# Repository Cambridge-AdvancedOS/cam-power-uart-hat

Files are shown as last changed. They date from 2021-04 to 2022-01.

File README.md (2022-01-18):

# Raspberry Pi Serial and Power Switching Hat

A Raspberry Pi Hat that provides USB serial access to the Pi's serial console. It allows for both power injection and switching via a JST-XH connector. There is also a combo temperature sensor/eeprom that can be accessed over USB.

Created for the [L41 Advanced Operating Systems](https://www.cl.cam.ac.uk/teaching/2021/L41/) course at UCAM CST.

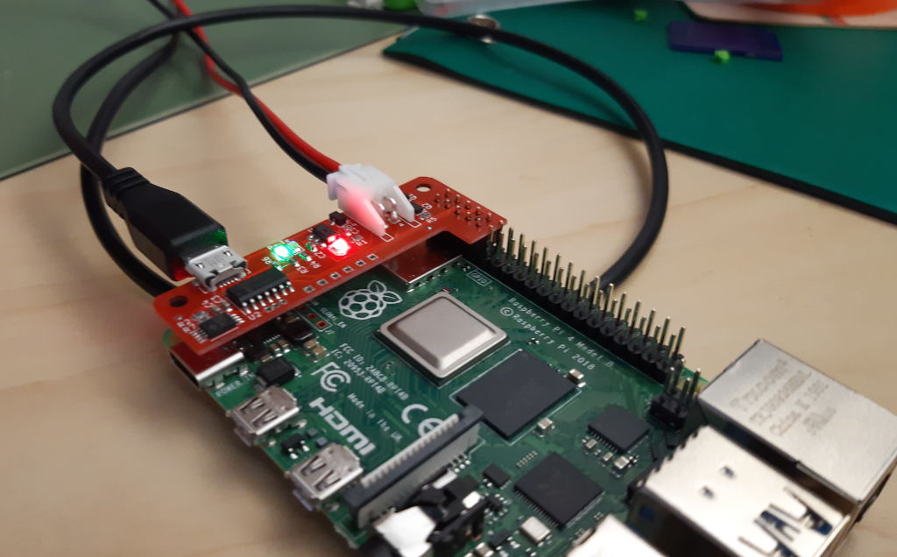
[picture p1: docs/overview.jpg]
Overview image showing the power hat attached to a RPi 4B


## Board Details

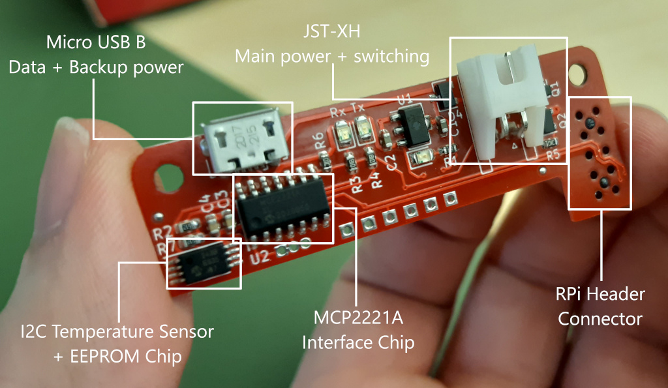
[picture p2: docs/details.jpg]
Detail view of the PCB with various chips labelled


### Notable ICs
* [MCP2221A](./docs/mcp2221a.pdf) - USB UART Interface chip, provides USB communications, GPIO control used for status LEDs and the power switching, and I2C interfacing to control the temperature sensor/eeprom.
* [MCP98243](./docs/mcp98243.pdf) - I2C temperature sensor and eeprom chip accessible via the MCP2221A. Could be substituted for other I2C chips as long as the power/GND and I2C pins match.
* [RQ5C060BC](./docs/rq5c060bc.pdf) - High power Pch MOSFET, can be substituted for any other high power (min 3A) MOSFET with a low gate threshold (must fully activate at Vgs = 3v3) and a GSD pin arrangement.

### Connectors
* Micro USB - Provides USB data and can provide power to the onboard ICs in the absense of the JST connector. No power is passed forward to the RPi however, so it cannot be powered from a single USB cable.
* [JST-XH](./docs/jst-xh.pdf) - Main power supply for the RPi, cables should be fitted with XHP-2 connectors with +ve on pin 1 and -ve on pin 2.
* RPi connector - Fits to the top end of the RPi GPIO header, uses a minimum of pins and leaves the remainder for other interaction.

## License

Designed by Thomas Bytheway for University of Cambridge.

Schematic details inspired by:
### [Adafruit-MCP2221](https://github.com/adafruit/Adafruit-MCP2221-PCB)
Designed by Limor Fried/Ladyada for Adafruit Industries.

### [Adafruit-PiUART](https://github.com/adafruit/Adafruit-PiUART-PCB)
Designed by Limor Fried/Ladyada for Adafruit Industries.

Creative Commons Attribution/Share-Alike, all text above must be included in any redistribution. See license.txt for additional details.

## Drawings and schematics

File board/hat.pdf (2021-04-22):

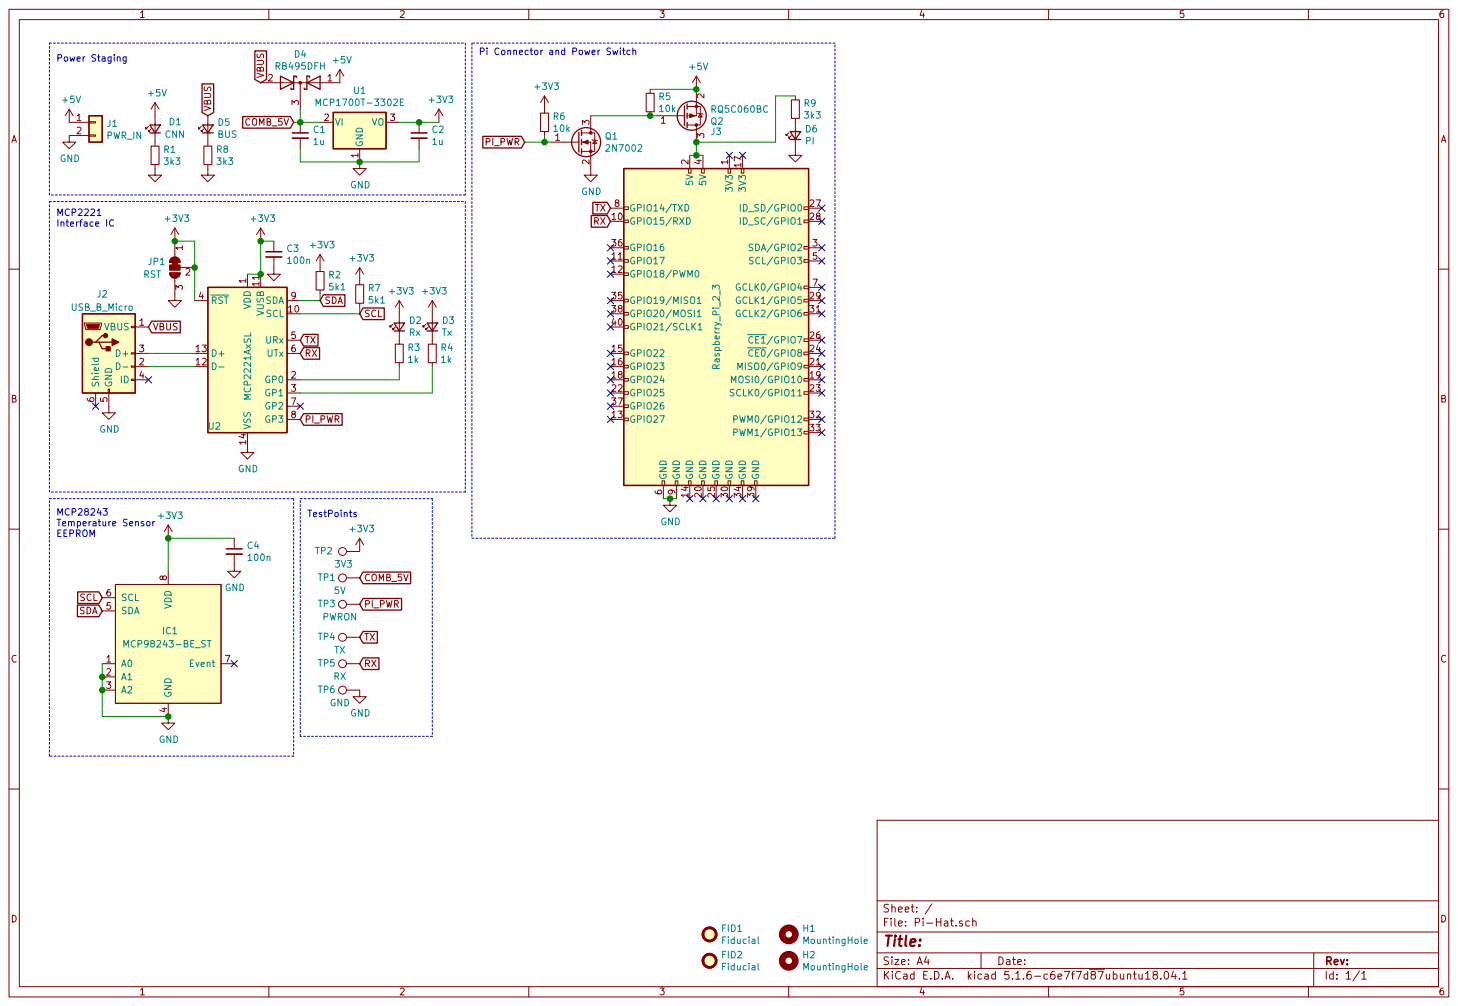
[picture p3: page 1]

TXRX VBUS
3k3 D5 BUS
Interface IC MCP28243 Temperature Sensor EEPROM

Pi Connector and Power Switch Power Staging MCP2221

1 SCL VUSB 10 11 D- 12 D+ 13 VSS 14 GP0 2 GP1 3 RST 4 URx 5 UTx 6 GP2 7 GP3 8 SDA 9 U2 MCP2221AxSL TP5RX

4 SDA 5 SCL 6 Event 7 VDD

Id: 1/1 Title: File: Pi-Hat.sch Sheet: / GND

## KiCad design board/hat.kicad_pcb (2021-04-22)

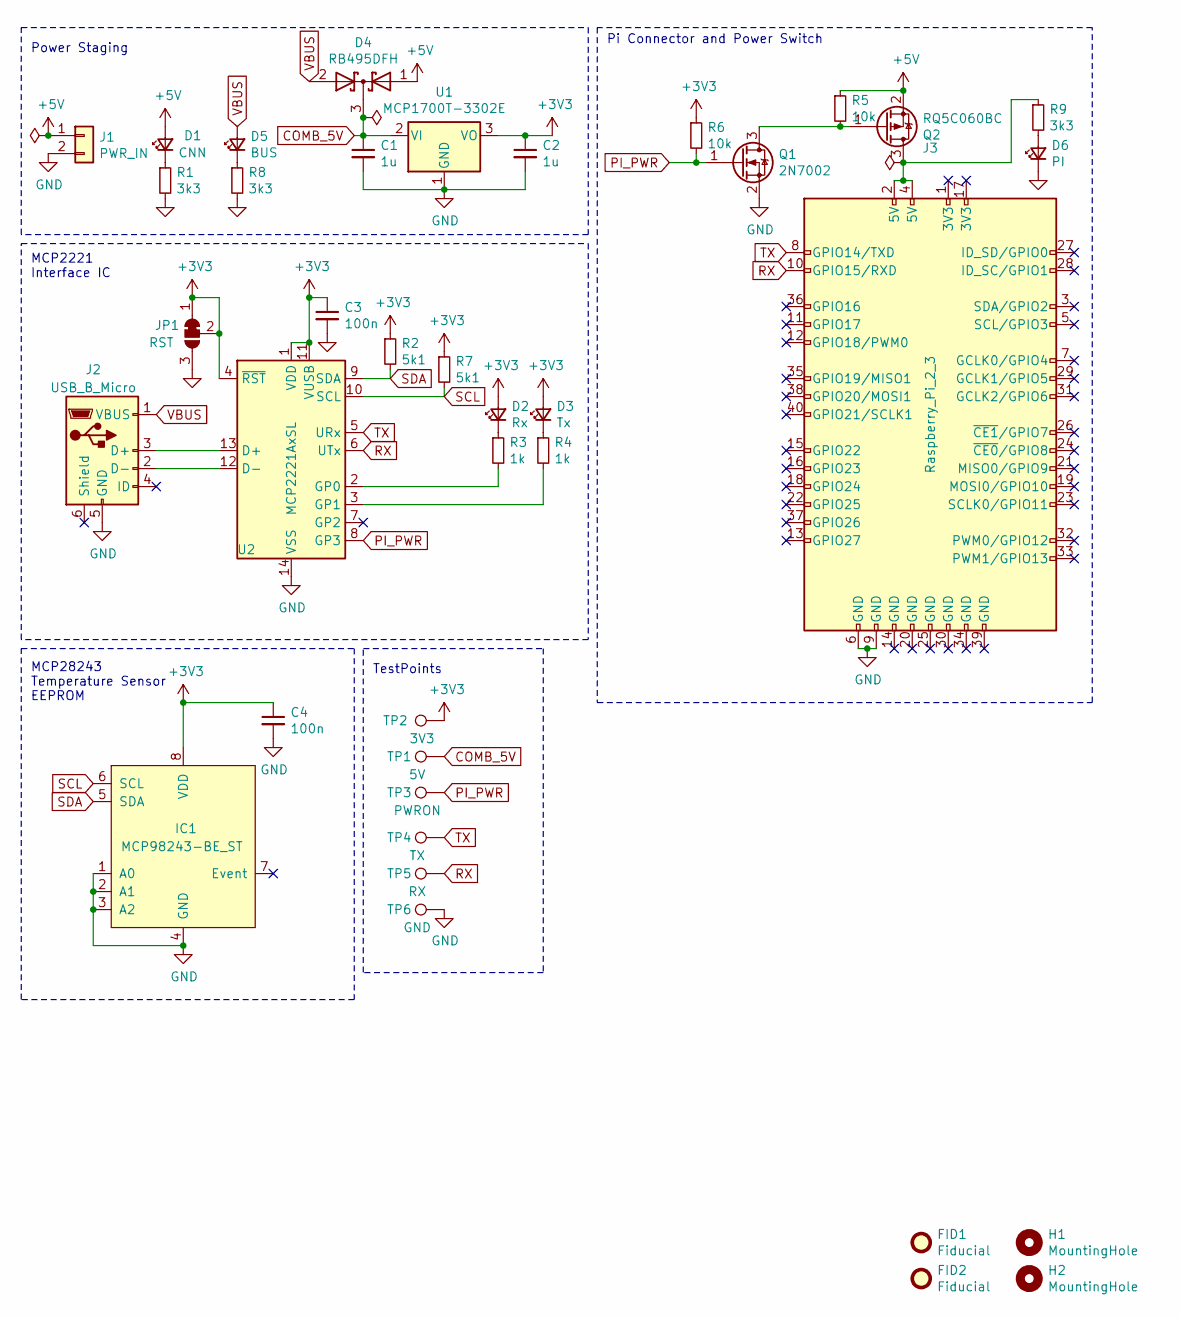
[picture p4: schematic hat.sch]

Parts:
C1, C2: 1u; C_0603_1608Metric
C3, C4: 100n; C_0603_1608Metric
D1: CNN; LED_0805_2012Metric; Farnell 2610416
D2: Rx; LED_0805_2012Metric; Farnell 2610419
D3: Tx; LED_0805_2012Metric; Farnell 2610420
D4: RB495DFH; SC-59; Farnell 2772677
D5: BUS; LED_0805_2012Metric; Farnell 2610416
D6: PI; LED_0805_2012Metric; Farnell 2610416
FID1, FID2: Fiducial; Fiducial_0.75mm_Mask1.5mm
H1, H2: MountingHole; MountingHole_2.7mm_M2.5
IC1: MCP98243-BE_ST; TSSOP-8_4.4x3mm_P0.65mm; Mouser 579-MCP98243-BE/ST
J1: PWR_IN; JST_XH_S2B-XH-A-1_1x02_P2.50mm_Horizontal; Farnell 1516289
J2: USB_B_Micro; USB_Micro-B_Molex-105017-0001; Farnell 2293836
J3: Raspberry_Pi_2_3; Samtec_HLE-105-02-xxx-DV-BE-A_2x05_P2.54mm_Horizontal; Mouser 200-HLE1052SDVBEAKTR
JP1: RST; PinHeader_1x03_P1.27mm_Vertical
Q1: 2N7002; SOT-23; Farnell 1713823
Q2: RQ5C060BC; SOT-23; Farnell 2706766
R1, R8, R9: 3k3; R_0603_1608Metric
R2, R7: 5k1; R_0603_1608Metric; Farnell 2447404
R3, R4: 1k; R_0603_1608Metric
R5, R6: 10k; R_0603_1608Metric
TP1: 5V; TestPoint_THTPad_1.5x1.5mm_Drill0.7mm
TP2: 3V3; TestPoint_THTPad_1.5x1.5mm_Drill0.7mm
TP3: PWRON; TestPoint_THTPad_1.5x1.5mm_Drill0.7mm
TP4: TX; TestPoint_THTPad_1.5x1.5mm_Drill0.7mm
TP5: RX; TestPoint_THTPad_1.5x1.5mm_Drill0.7mm
TP6: GND; TestPoint_THTPad_1.5x1.5mm_Drill0.7mm
U1: MCP1700T-3302E; SOT-89-3; Farnell 1439380
U2: MCP2221AxSL; SOIC-14_3.9x8.7mm_P1.27mm; Farnell 2678460

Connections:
+3V3: C2.1, C3.1, C4.1, D2.2 (A), D3.2 (A), IC1.8 (VDD), JP1.1 (A), JP1.2 (C), R2.1, R6.1, R7.1, TP2.1, U1.3 (VO), U2.1 (VDD), U2.4 (~RST), U2.11 (VUSB)
+5V: D1.2 (A), D4.1 (A), J1.1, Q2.2 (S), R5.1
COMB_5V: C1.1, D4.3 (K), TP1.1, U1.2 (VI)
GND: C1.2, C2.2, C3.2, C4.2, D6.1 (K), IC1.1 (A0), IC1.2 (A1), IC1.3 (A2), IC1.4 (GND), J1.2, J2.5 (GND), J3.6 (GND), J3.9 (GND), JP1.3 (B), Q1.2 (S), R1.2, R8.2, TP6.1, U1.1 (GND), U2.14 (VSS)
unnamed: D1.1 (K), R1.1
unnamed: D2.1 (K), R3.1
unnamed: D3.1 (K), R4.1
unnamed: D5.1 (K), R8.1
unnamed: D6.2 (A), R9.2
unnamed: J2.2 (D-), U2.12 (D-)
unnamed: J2.3 (D+), U2.13 (D+)
unnamed: J3.2 (5V), J3.4 (5V), Q2.3 (D), R9.1
unnamed: Q1.3 (D), Q2.1 (G), R5.2
unnamed: R3.2, U2.2 (GP0)
unnamed: R4.2, U2.3 (GP1)
PI_PWR: Q1.1 (G), R6.2, TP3.1, U2.8 (GP3)
RX: J3.10 (GPIO15/RXD), TP5.1, U2.6 (UTx)
SCL: IC1.6 (SCL), R7.2, U2.10 (SCL)
SDA: IC1.5 (SDA), R2.2, U2.9 (SDA)
TX: J3.8 (GPIO14/TXD), TP4.1, U2.5 (URx)
VBUS: D4.2 (A), D5.2 (A), J2.1 (VBUS)

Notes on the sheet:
Pi Connector and Power Switch
Power Staging
MCP2221 Interface IC
MCP28243 Temperature Sensor EEPROM
TestPoints

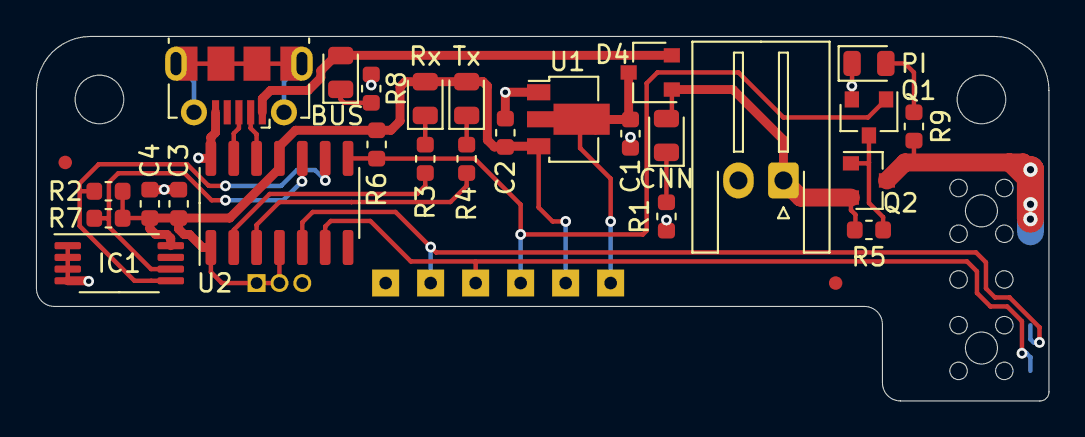
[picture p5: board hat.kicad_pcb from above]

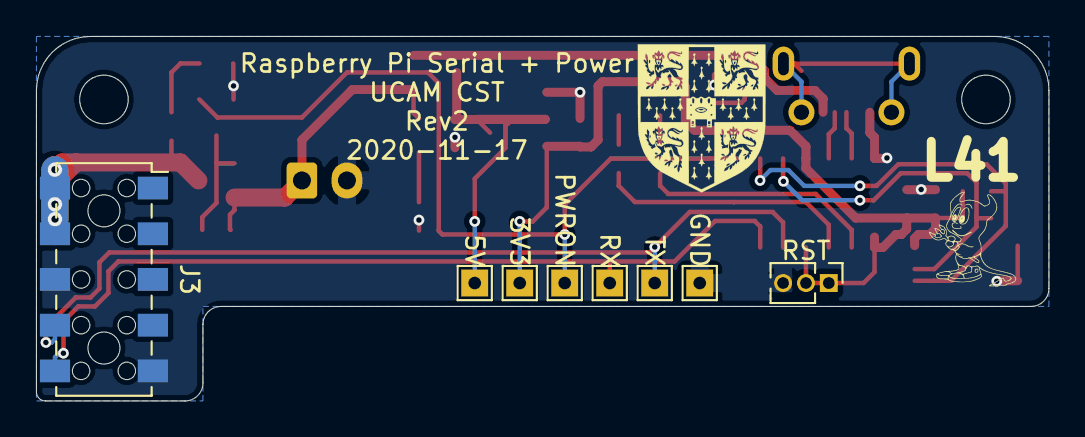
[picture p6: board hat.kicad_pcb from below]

Board: 2 copper layers, 56.2 x 20.2 mm, 38 parts (8 on the bottom side), 21 nets.
